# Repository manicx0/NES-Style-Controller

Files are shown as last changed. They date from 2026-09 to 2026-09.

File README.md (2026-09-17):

### NES-Style Modern Controller — Component List & Wiring Overview

An SoC with built-in WiFi+Bluetooth handles wireless duty, with an optional dedicated 2.4GHz nRF radio for a low-latency "wired-like" mode — a common approach in hobby gamepad builds since no single chip natively does WiFi+BT+proprietary-nRF all at once.

### Component List

**Brain**

- Main MCU/SoC with built-in WiFi + Bluetooth (e.g. an ESP32-class chip) — handles button/stick polling, display driving, and wireless output
- Optional secondary 2.4GHz radio module (nRF24L01+ style) for a dedicated low-latency "nRF mode," wired to the MCU over SPI

**Input**

- 2x analog stick modules (dual-potentiometer + click-button type, PSP/Joy-Con style)
- D-pad (4-way cross, either 4 discrete tactile switches or a single 4/8-way rocker module)
- 4x face buttons (tactile switches)
- Start/Select buttons
- 1-2x dedicated "menu/mode" buttons for navigating the mini display's settings UI (can double up with Start/Select if you want to save parts)
- Tactile switch caps / keycaps for the above

**Display**

- Small SPI or I2C TFT/OLED display (roughly 0.9"–1.5" is typical for a corner status screen)

**Power**

- LiPo battery (single-cell, capacity to taste)
- Battery charge/protection module (handles USB-C charging + over-discharge protection)
- 3.3V voltage regulator (if your battery/charger output doesn't already give clean 3.3V)
- USB-C connector (charging + optional wired/data mode)
- Power slide switch

**Support**

- Pull-down (or pull-up) resistors for each button line, unless using MCU internal pull resistors
- Small decoupling capacitors near MCU and radio modules
- Status LED(s) (battery/pairing indicator — optional)
- Protoboard or custom PCB
- 3D-printed or laser-cut rectangular shell (NES-004 proportions, no shoulder-button cutouts)

## Acknowledgments / Inspiration

Design inspired by the NES 004 controller form factor.

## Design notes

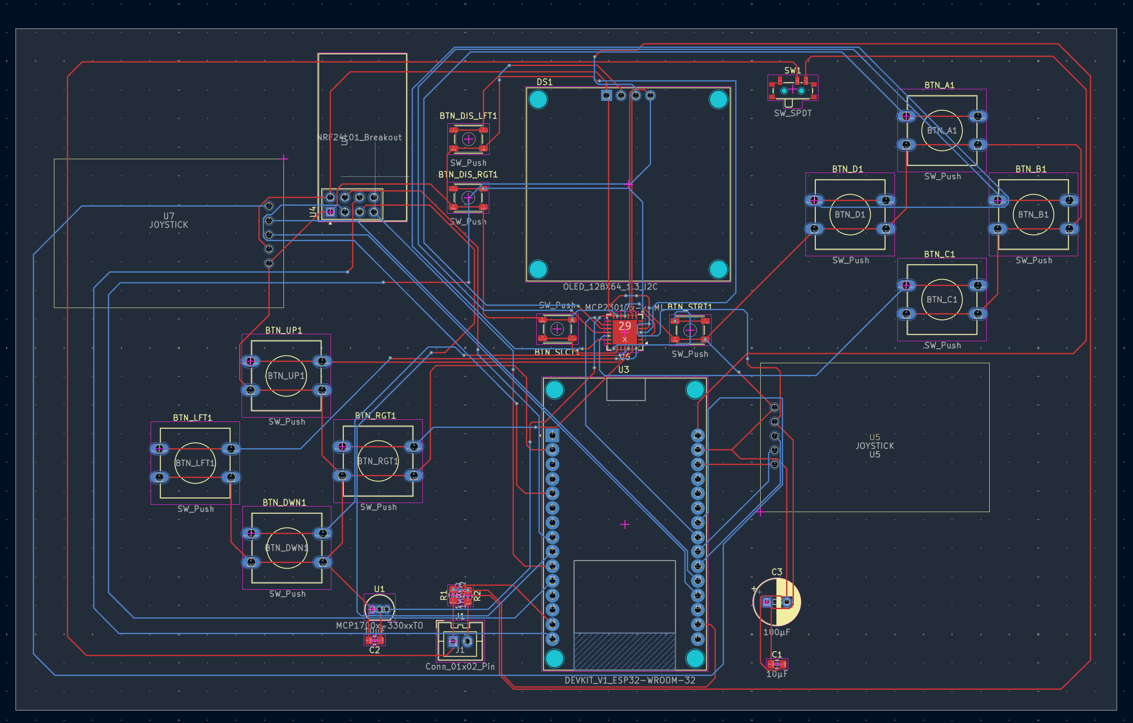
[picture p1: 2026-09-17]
hardware/export/pcb.png

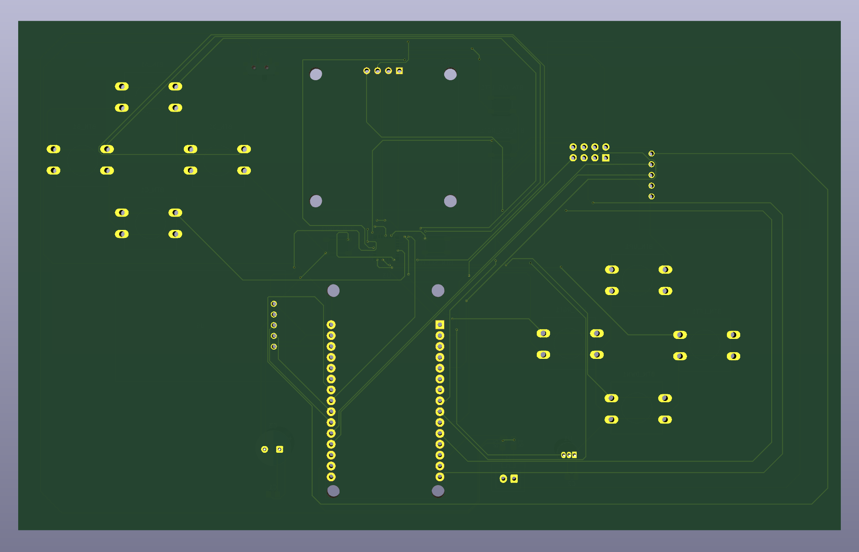
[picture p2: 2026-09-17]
hardware/export/pcb-back.png

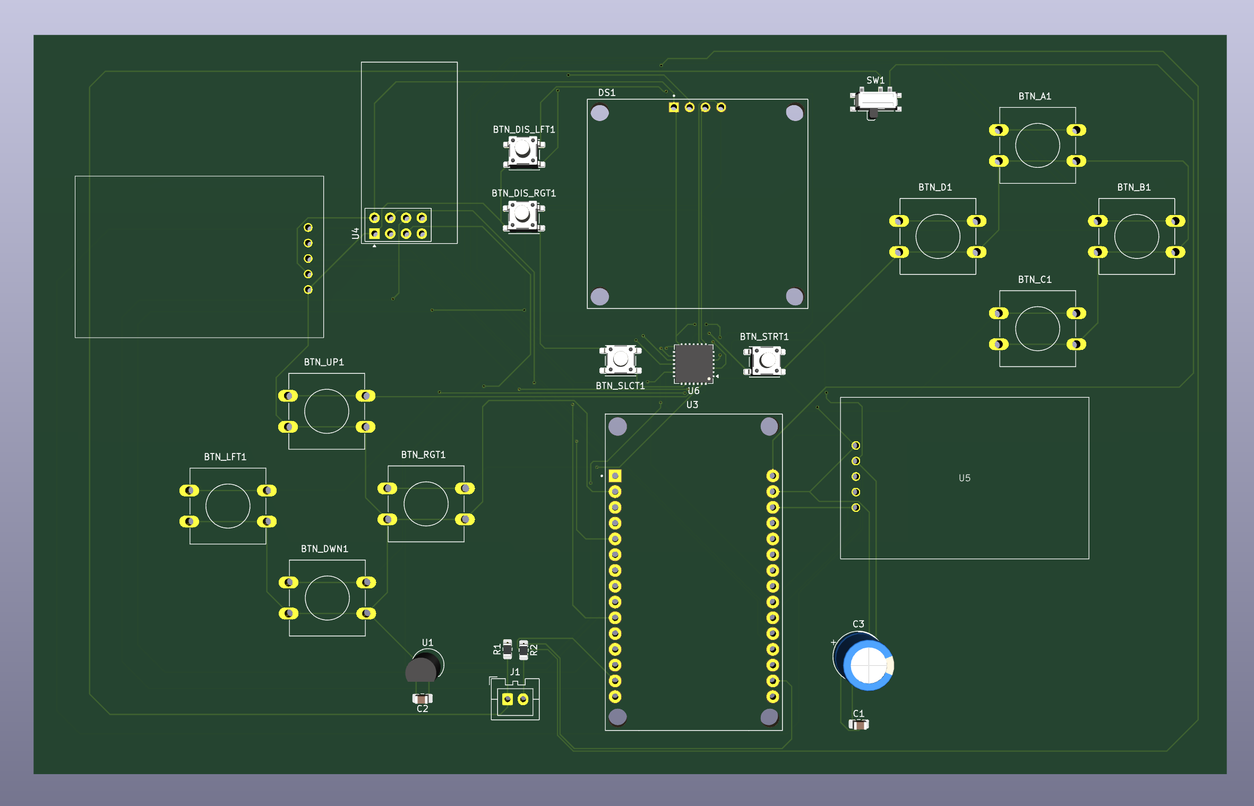
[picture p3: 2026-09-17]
hardware/export/pcb-front.png

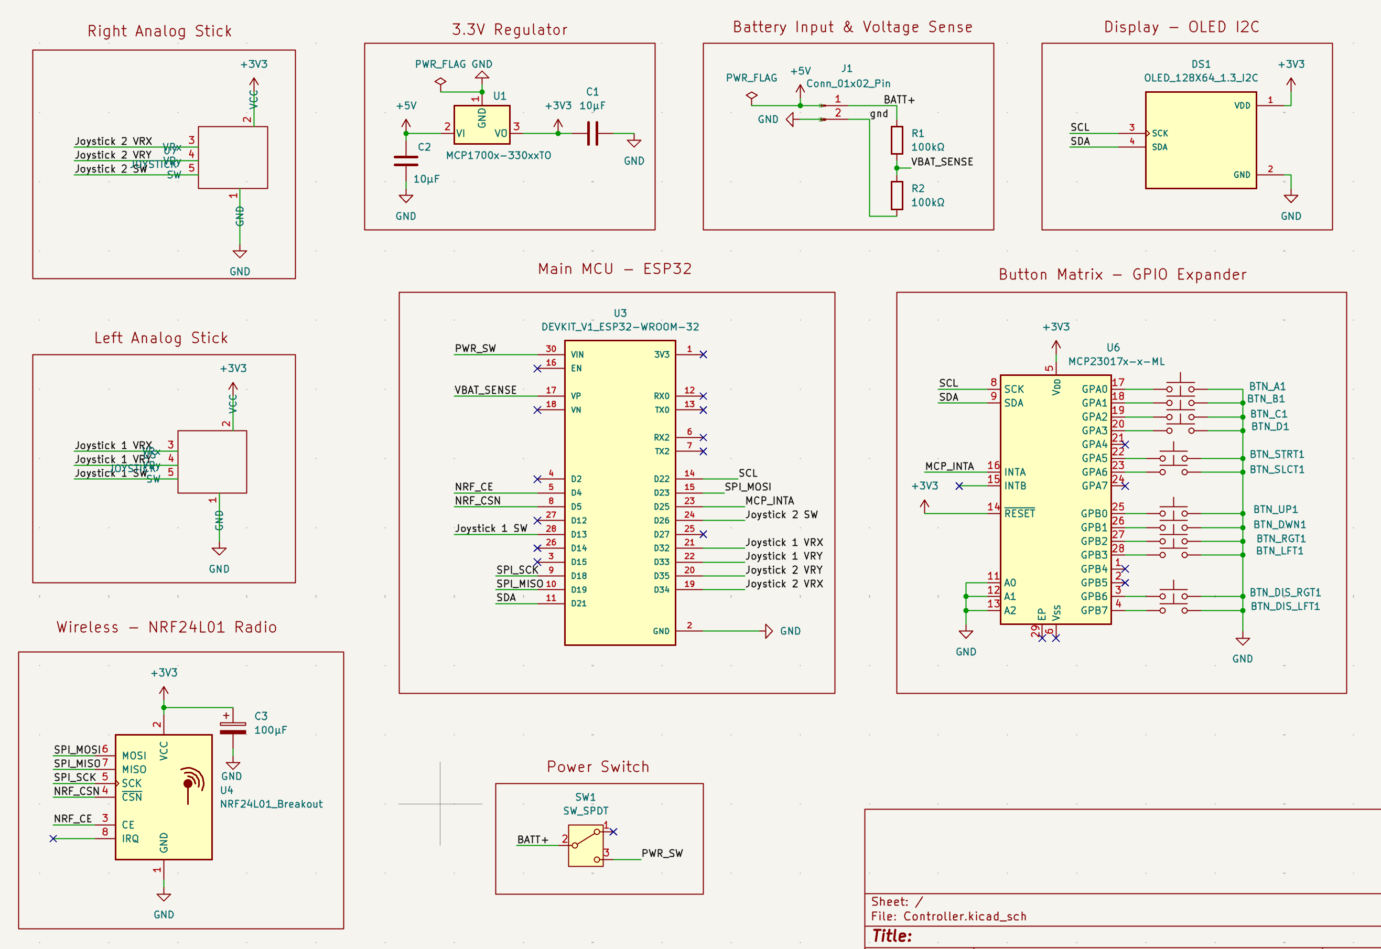
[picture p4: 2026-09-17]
hardware/export/schematic.png

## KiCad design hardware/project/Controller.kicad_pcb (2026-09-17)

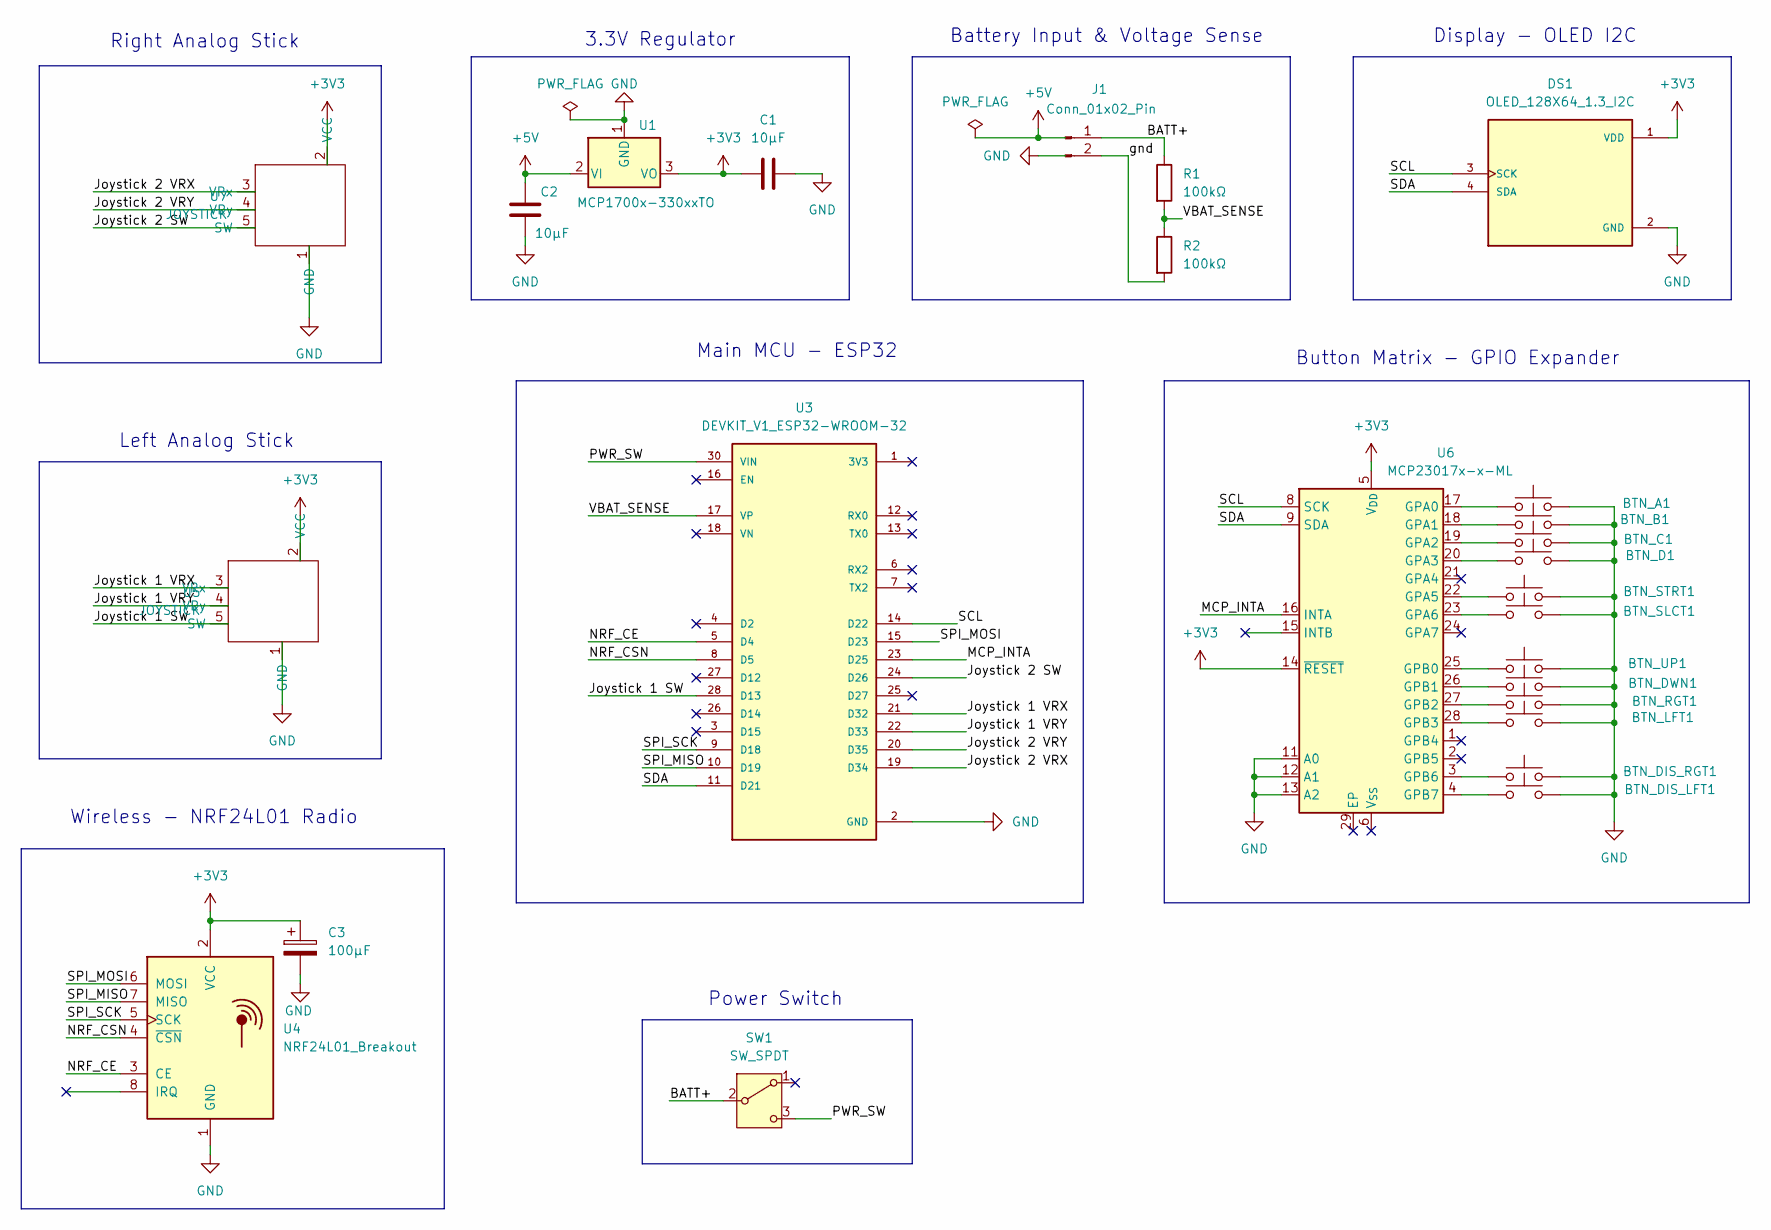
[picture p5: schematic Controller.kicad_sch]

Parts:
BTN_A1: SW_Push; SW_PUSH-12mm
BTN_B1: SW_Push; SW_PUSH-12mm
BTN_C1: SW_Push; SW_PUSH-12mm
BTN_D1: SW_Push; SW_PUSH-12mm
BTN_DIS_LFT1: SW_Push; SW_SPST_PTS647_Sx50
BTN_DIS_RGT1: SW_Push; SW_SPST_PTS647_Sx50
BTN_DWN1: SW_Push; SW_PUSH-12mm
BTN_LFT1: SW_Push; SW_PUSH-12mm
BTN_RGT1: SW_Push; SW_PUSH-12mm
BTN_SLCT1: SW_Push; SW_SPST_PTS647_Sx50
BTN_STRT1: SW_Push; SW_SPST_PTS647_Sx50
BTN_UP1: SW_Push; SW_PUSH-12mm
C1, C2: 10µF; C_0805_2012Metric_Pad1.18x1.45mm_HandSolder
C3: 100µF; CP_Radial_D8.0mm_P3.50mm
DS1: OLED_128X64_1.3_I2C; LCD_OLED_128X64_1.3_I2C; PARTREV NA
J1: Conn_01x02_Pin; JST_XA_B02B-XASK-1_1x02_P2.50mm_Vertical
R1, R2: 100kΩ; R_0805_2012Metric_Pad1.20x1.40mm_HandSolder
SW1: SW_SPDT; SW_SPDT_PCM12
U1: MCP1700x-330xxTO; TO-92_Inline
U3: DEVKIT_V1_ESP32-WROOM-32; MODULE_DEVKIT_V1_ESP32-WROOM-32
U4: NRF24L01_Breakout; nRF24L01_Breakout
U5, U7: JOYSTICK
U6: MCP23017x-x-ML; QFN-28-1EP_6x6mm_P0.65mm_EP4.25x4.25mm

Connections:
+3V3: C1.1, C3.1, DS1.1 (VDD), U1.3 (VO), U4.2 (VCC), U5.2 (VCC), U6.5 (V_{DD}), U6.14 (~RESET), U7.2 (VCC)
+5V: C2.1, U1.2 (VI)
/BATT+: J1.1, R1.1, SW1.2 (B)
/Joystick 1 SW: U3.28 (D13), U5.5 (SW)
/Joystick 1 VRX: U3.21 (D32), U5.3 (VRx)
/Joystick 1 VRY: U3.22 (D33), U5.4 (VRy)
/Joystick 2 SW: U3.24 (D26), U7.5 (SW)
/Joystick 2 VRX: U3.19 (D34), U7.3 (VRx)
/Joystick 2 VRY: U3.20 (D35), U7.4 (VRy)
/MCP_INTA: U3.23 (D25), U6.16 (INTA)
/NRF_CE: U3.5 (D4), U4.3 (CE)
/NRF_CSN: U3.8 (D5), U4.4 (~CSN)
/PWR_SW: SW1.3 (C), U3.30 (VIN)
/SCL: DS1.3 (SCK), U3.14 (D22), U6.8 (SCK)
/SDA: DS1.4 (SDA), U3.11 (D21), U6.9 (SDA)
/SPI_MISO: U3.10 (D19), U4.7 (MISO)
/SPI_MOSI: U3.15 (D23), U4.6 (MOSI)
/SPI_SCK: U3.9 (D18), U4.5 (SCK)
/VBAT_SENSE: R1.2, R2.1, U3.17 (VP)
/gnd: J1.2, R2.2
GND: BTN_A1.2, BTN_B1.2, BTN_C1.2, BTN_D1.2, BTN_DIS_LFT1.2, BTN_DIS_RGT1.2, BTN_DWN1.2, BTN_LFT1.2, BTN_RGT1.2, BTN_SLCT1.2, BTN_STRT1.2, BTN_UP1.2, C1.2, C2.2, C3.2, DS1.2 (GND), U1.1 (GND), U3.2 (GND), U3.29 (GND), U4.1 (GND), U5.1 (GND), U6.11 (A0), U6.12 (A1), U6.13 (A2), U7.1 (GND)
unnamed: BTN_A1.1, U6.17 (GPA0)
unnamed: BTN_B1.1, U6.18 (GPA1)
unnamed: BTN_C1.1, U6.19 (GPA2)
unnamed: BTN_D1.1, U6.20 (GPA3)
unnamed: BTN_STRT1.1, U6.22 (GPA5)
unnamed: BTN_SLCT1.1, U6.23 (GPA6)
unnamed: BTN_UP1.1, U6.25 (GPB0)
unnamed: BTN_DWN1.1, U6.26 (GPB1)
unnamed: BTN_RGT1.1, U6.27 (GPB2)
unnamed: BTN_LFT1.1, U6.28 (GPB3)
unnamed: BTN_DIS_RGT1.1, U6.3 (GPB6)
unnamed: BTN_DIS_LFT1.1, U6.4 (GPB7)

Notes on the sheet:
Wireless - NRF24L01 Radio
Right Analog Stick
Main MCU - ESP32
Button Matrix - GPIO Expander
3.3V Regulator
Left Analog Stick
Power Switch
Battery Input & Voltage Sense
Display - OLED I2C

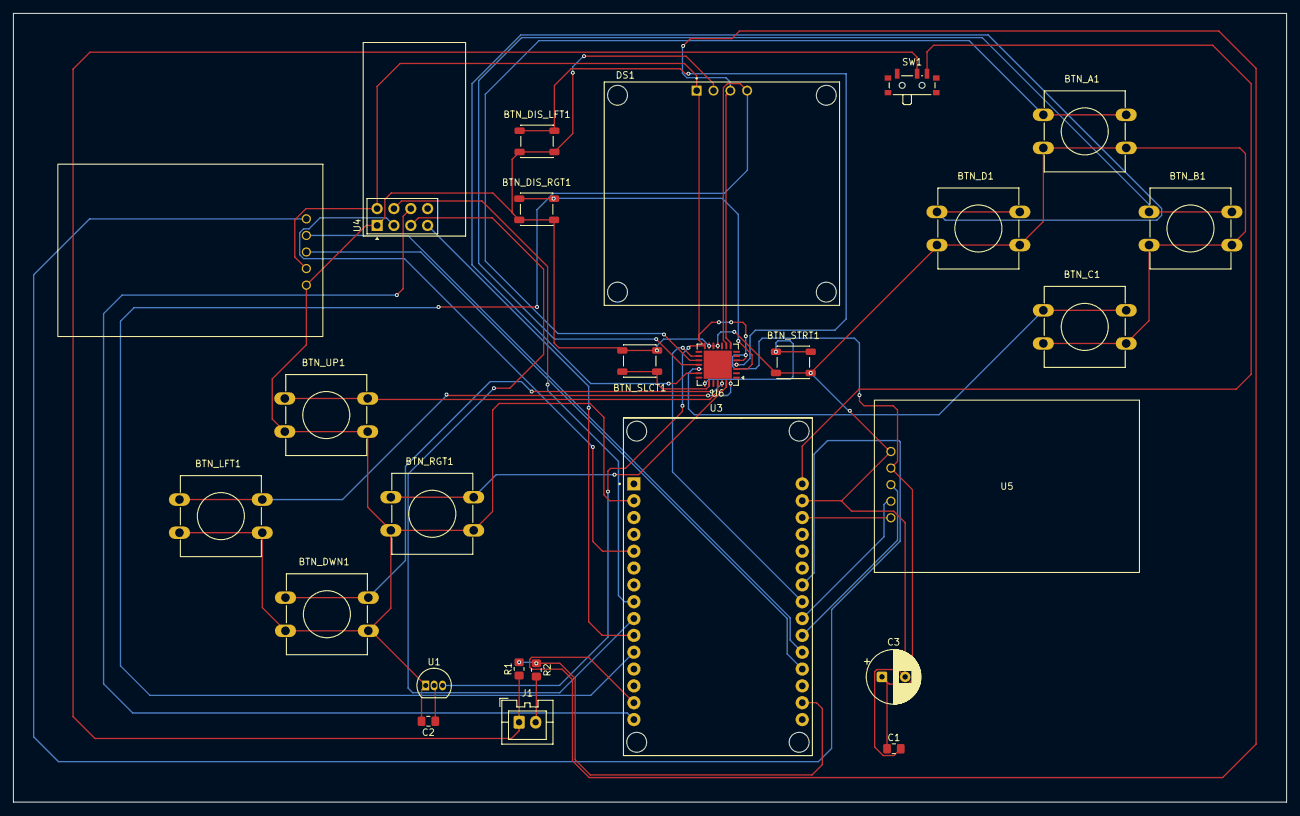
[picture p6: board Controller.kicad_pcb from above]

Board: 2 copper layers, 192.1 x 119.0 mm, 26 parts (0 on the bottom side), 33 nets.
